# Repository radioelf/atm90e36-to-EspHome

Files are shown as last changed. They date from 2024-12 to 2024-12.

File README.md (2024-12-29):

Código para el IC ATM90e36 para usar con EspHome

Code for the ATM90e36 IC to use with ESPHome

Creative Commons License Disclaimer

UNLESS OTHERWISE MUTUALLY AGREED TO BY THE PARTIES IN WRITING, LICENSOR OFFERS THE WORK AS-IS AND MAKES NO REPRESENTATIONS OR WARRANTIES OF ANY KIND CONCERNING THE WORK, EXPRESS, IMPLIED, STATUTORY OR OTHERWISE, INCLUDING, WITHOUT LIMITATION, WARRANTIES OF TITLE, MERCHANTIBILITY, FITNESS FOR A PARTICULAR PURPOSE, NONINFRINGEMENT, OR THE ABSENCE OF LATENT OR OTHER DEFECTS, ACCURACY, OR THE PRESENCE OF ABSENCE OF ERRORS, WHETHER OR NOT DISCOVERABLE. SOME JURISDICTIONS DO NOT ALLOW THE EXCLUSION OF IMPLIED WARRANTIES, SO SUCH EXCLUSION MAY NOT APPLY TO YOU. EXCEPT TO THE EXTENT REQUIRED BY APPLICABLE LAW, IN NO EVENT WILL LICENSOR BE LIABLE TO YOU ON ANY LEGAL THEORY FOR ANY SPECIAL, INCIDENTAL, CONSEQUENTIAL, PUNITIVE OR EXEMPLARY DAMAGES ARISING OUT OF THIS LICENSE OR THE USE OF THE WORK, EVEN IF LICENSOR HAS BEEN ADVISED OF THE POSSIBILITY OF SUCH DAMAGES.

http://creativecommons.org/licenses/by-sa/3.0/

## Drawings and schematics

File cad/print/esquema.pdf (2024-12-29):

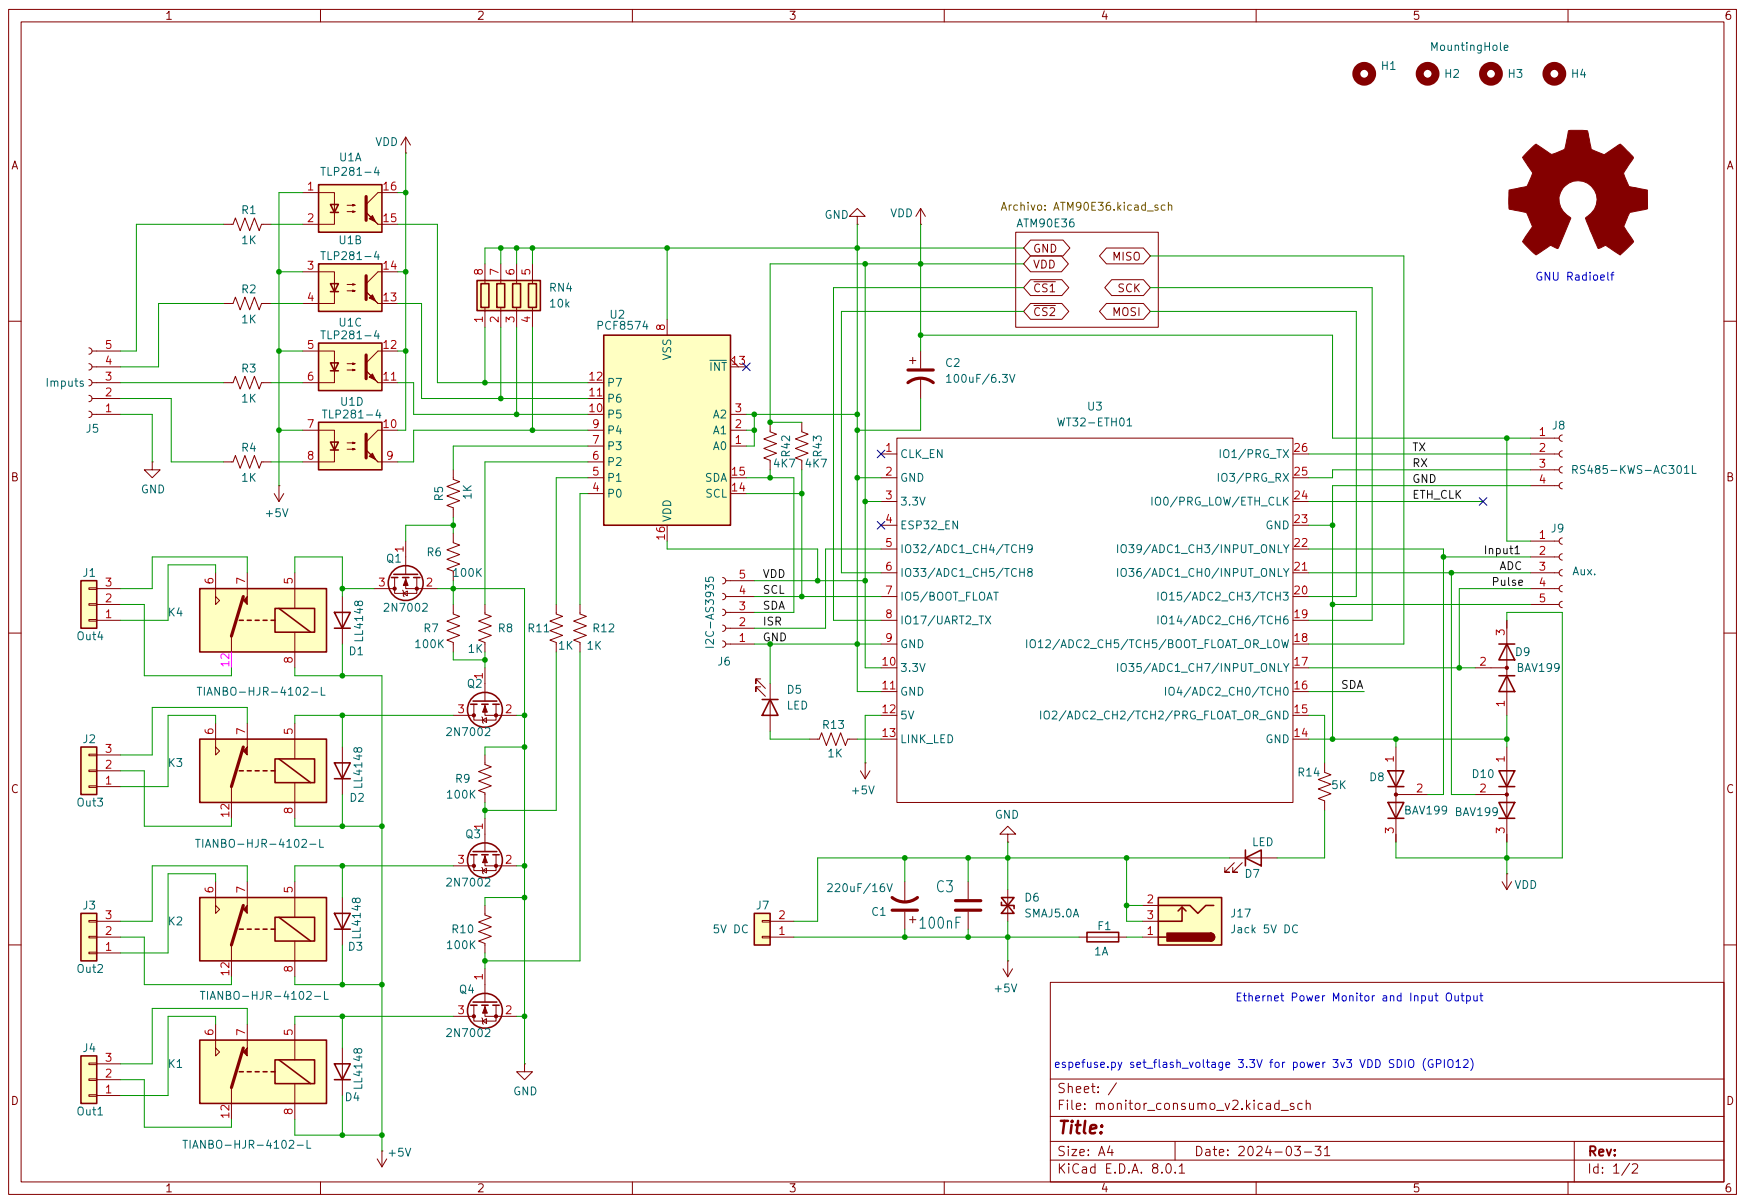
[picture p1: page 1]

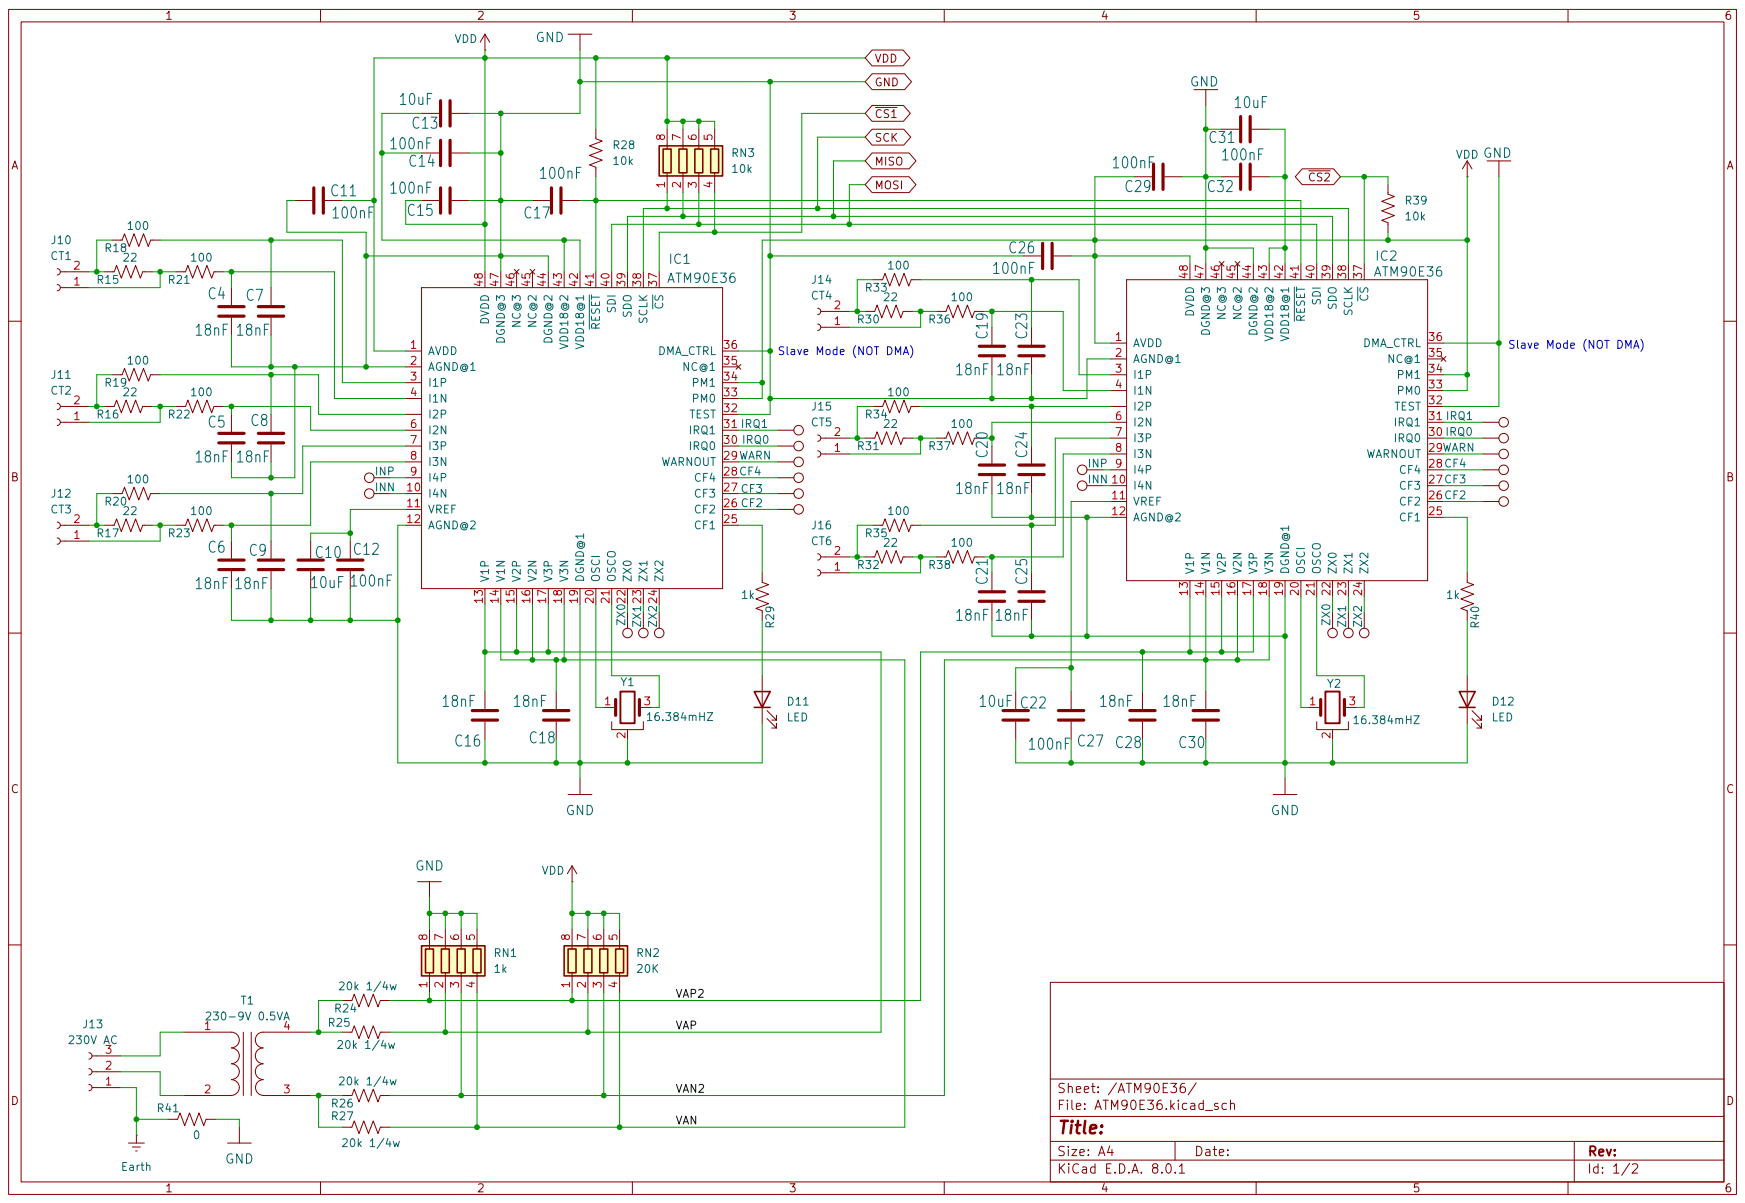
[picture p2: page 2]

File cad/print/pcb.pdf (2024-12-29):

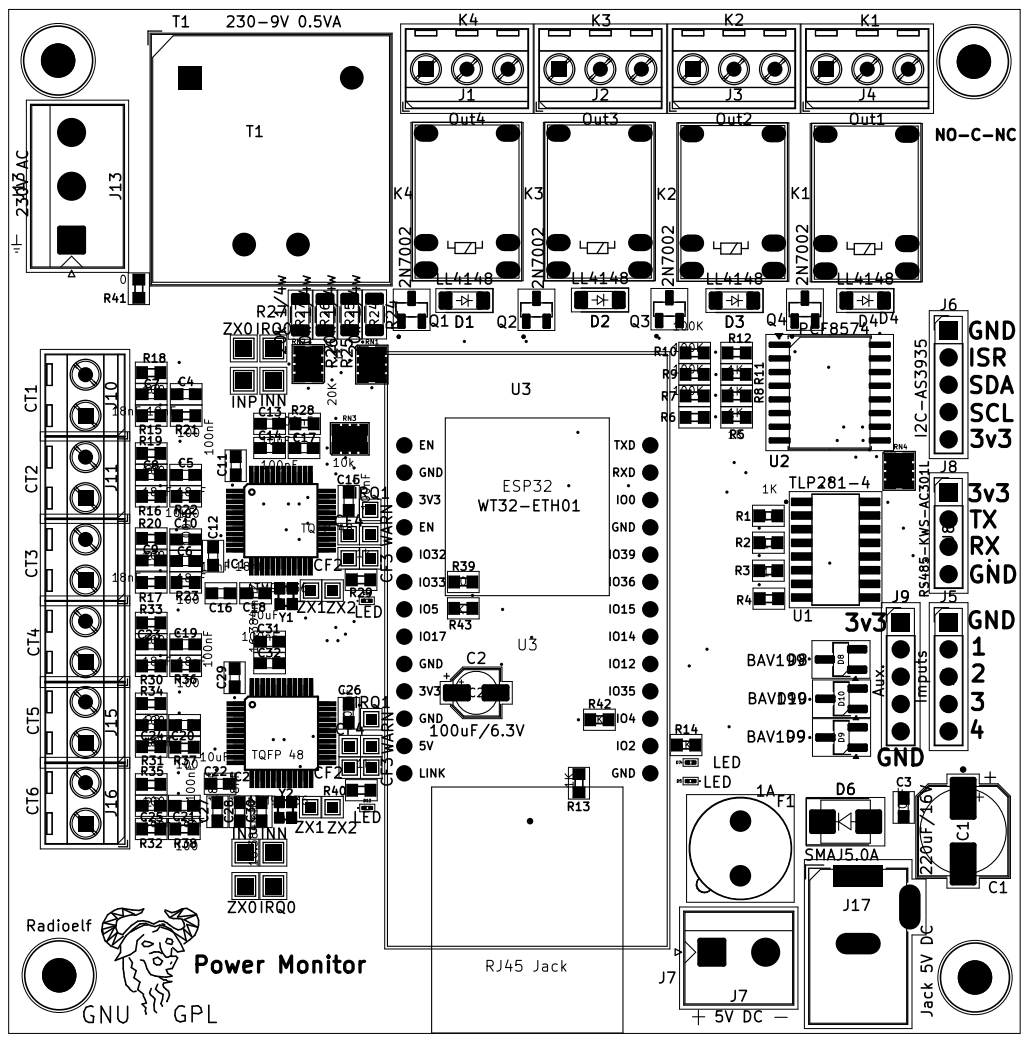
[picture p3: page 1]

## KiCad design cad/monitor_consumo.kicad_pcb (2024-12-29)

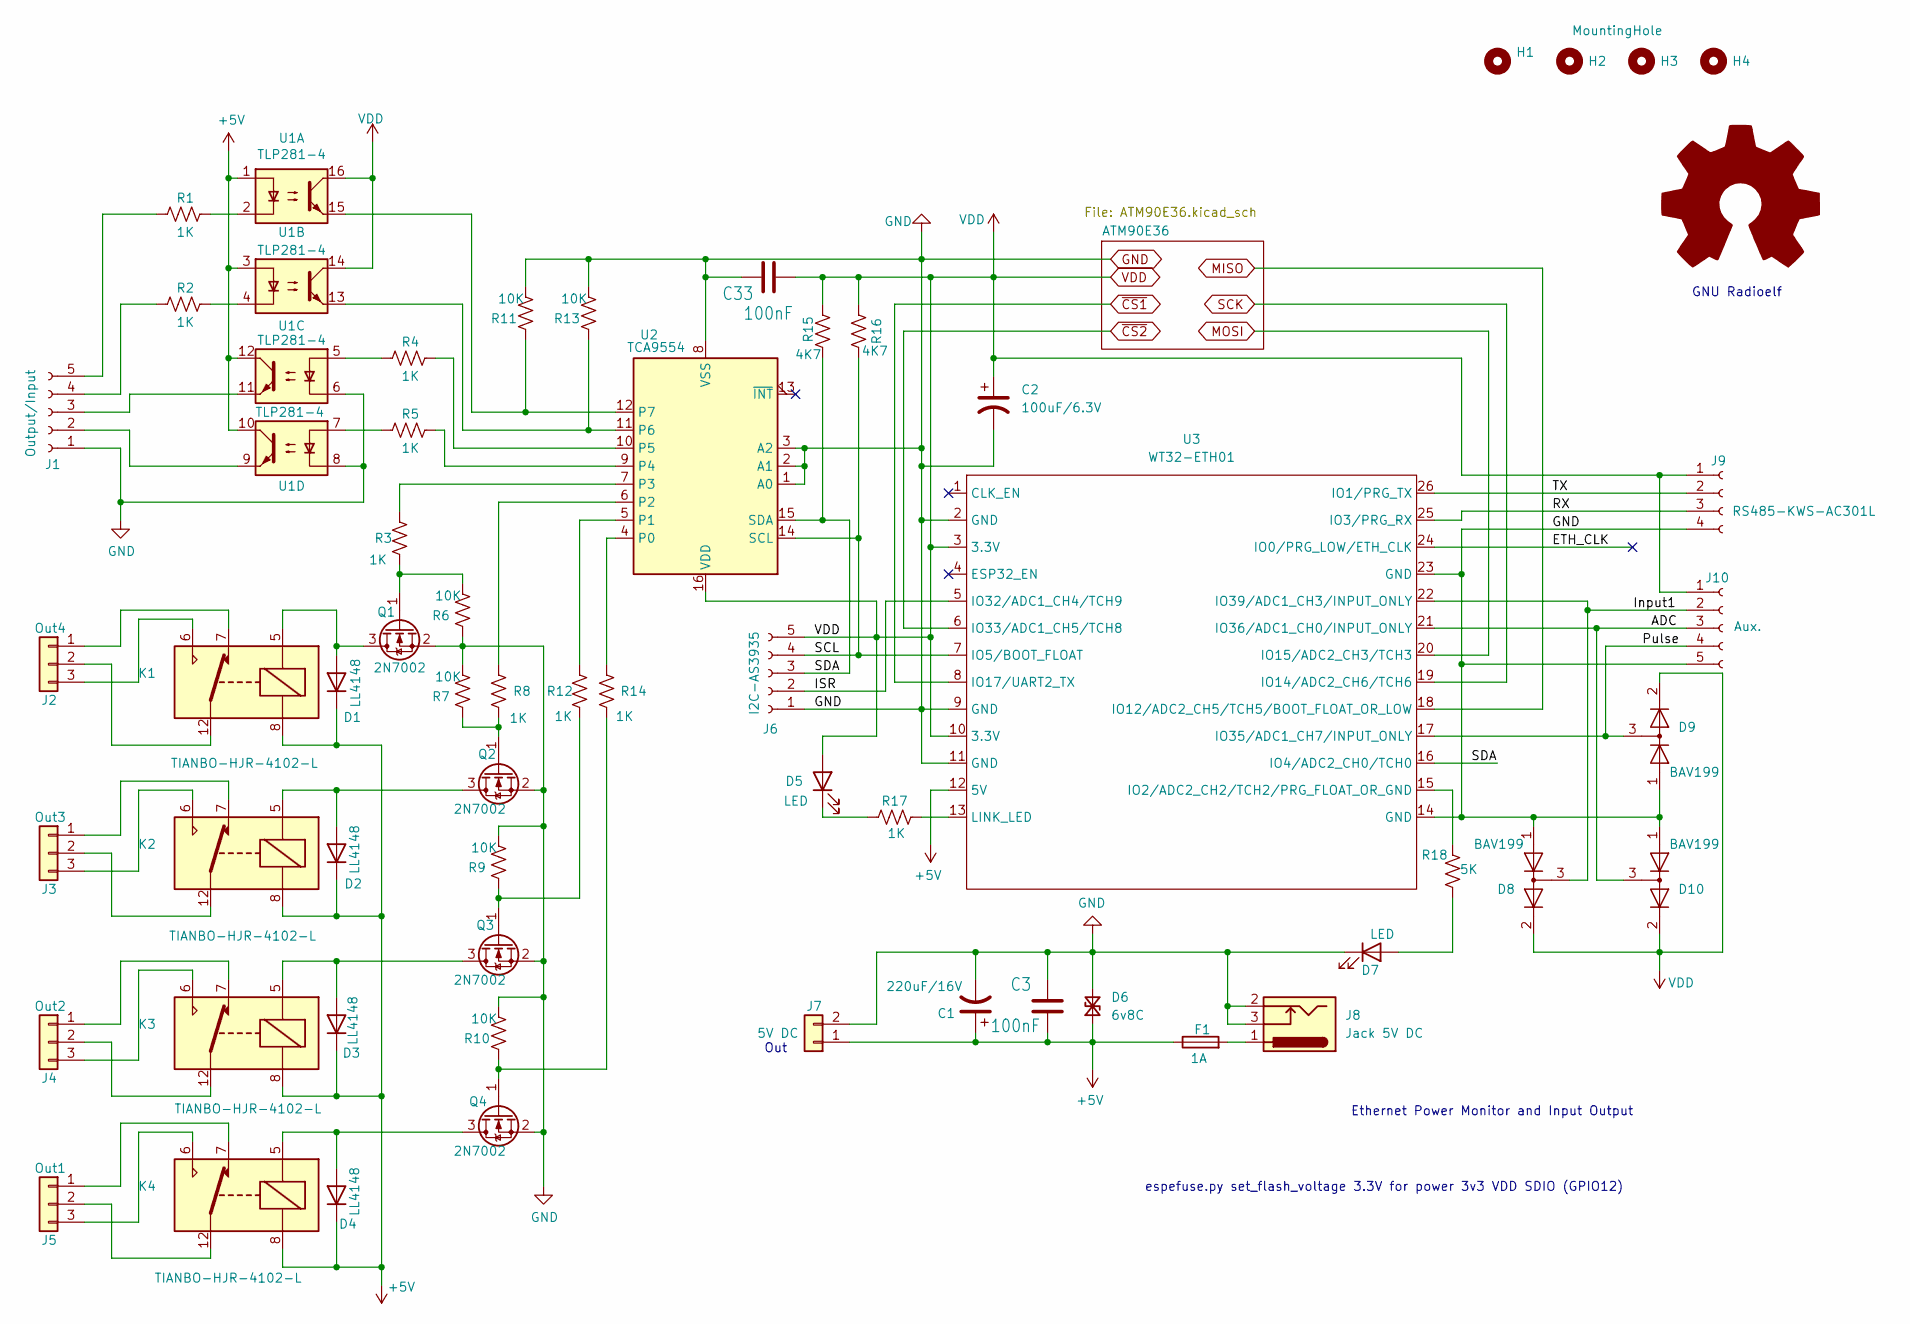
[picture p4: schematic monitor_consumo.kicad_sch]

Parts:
C1: 220uF/16V; CP_Elec_8x5.4
C2: 100uF/6.3V; CP_Elec_4x5.4
C3, C33: 100nF; C0603
D1, D2, D3, D4: LL4148; D_MiniMELF
D5, D7: LED; LED_0603_1608Metric
D6: 6v8C; D_SMB
D8, D9, D10: BAV199; SOT-23
F1: 1A; Fuseholder_TR5_Littelfuse_No560_No460
H1, H2, H3, H4: MountingHole; MountingHole_3.2mm_M3
J1: Output/Input; PinHeader_1x05_P2.54mm_Vertical
J2: Out4; TerminalBlock_Phoenix_PT-1,5-3-3.5-H_1x03_P3.50mm_Horizontal
J3: Out3; TerminalBlock_Phoenix_PT-1,5-3-3.5-H_1x03_P3.50mm_Horizontal
J4: Out2; TerminalBlock_Phoenix_PT-1,5-3-3.5-H_1x03_P3.50mm_Horizontal
J5: Out1; TerminalBlock_Phoenix_PT-1,5-3-3.5-H_1x03_P3.50mm_Horizontal
J6: I2C-AS3935; PinHeader_1x05_P2.54mm_Vertical
J7: 5V DC; JST_NV_B02P-NV_1x02_P5.00mm_Vertical
J8: Jack 5V DC; BarrelJack_GCT_DCJ200-10-A_Horizontal
J9: RS485-KWS-AC301L; PinHeader_1x04_P2.54mm_Vertical
J10: Aux.; PinHeader_1x05_P2.54mm_Vertical
K1, K2, K3, K4: TIANBO-HJR-4102-L; Relay_SPDT_HJR-4102
Q1, Q2, Q3, Q4: 2N7002; 2N7002-SOT95P240X111-3N
R1, R2, R3, R4, R5, R8, R12, R14, R17: 1K; R0603
R6, R7, R9, R10, R11, R13: 10K; R0603
R15, R16: 4K7; R0603
R18: 5K; R0603
U1: TLP281-4; SOIC127P700X210-16N
U2: TCA9554; SOIC-16W_7.5x10.3mm_P1.27mm
U3: WT32-ETH01

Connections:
+5V: C1.1, C3.2, D1.1 (K), D2.1 (K), D3.1 (K), D4.1 (K), D6.1 (A1), F1.1, J7.1, K1.8, K2.8, K3.8, K4.8, U1.1, U1.3, U1.10, U1.12, U3.12 (5V)
/ADC: D10.3 (K), J10.3, U3.21 (IO36/ADC1_CH0/INPUT_ONLY)
/ETH_CLK: U3.24 (IO0/PRG_LOW/ETH_CLK)
/ISR: J6.2, U3.5 (IO32/ADC1_CH4/TCH9)
/Input1: D8.3 (K), J10.2, U3.22 (IO39/ADC1_CH3/INPUT_ONLY)
/Pulse: D9.3 (K), J10.4, U3.17 (IO35/ADC1_CH7/INPUT_ONLY)
/RX: J9.3, U3.25 (IO3/PRG_RX)
/SCL: J6.4, R16.1, U2.14 (SCL), U3.7 (IO5/BOOT_FLOAT)
/SDA: J6.3, R15.1, U2.15 (SDA), U3.16 (IO4/ADC2_CH0/TCH0)
/TX: J9.2, U3.26 (IO1/PRG_TX)
GND: C1.2, C2.2, C3.1, C33.1, D6.2 (A2), D7.1 (K), D8.1 (K), D9.1 (K), D10.1 (K), J1.1, J6.1, J7.2, J8.2, J8.3, J9.4, J10.5, Q1.2 (S), Q2.2 (S), Q3.2 (S), Q4.2 (S), R6.1, R7.2, R9.2, R10.2, R11.2, R13.2, U1.6, U1.8, U2.1 (A0), U2.2 (A1), U2.3 (A2), U2.8 (VSS), U3.2 (GND), U3.9 (GND), U3.11 (GND), U3.14 (GND), U3.23 (GND); also elsewhere on the board
MISO: U3.18 (IO12/ADC2_CH5/TCH5/BOOT_FLOAT_OR_LOW); also elsewhere on the board
MOSI: U3.20 (IO15/ADC2_CH3/TCH3); also elsewhere on the board
unnamed: D1.2 (A), K1.5, Q1.3 (D)
unnamed: D2.2 (A), K2.5, Q2.3 (D)
unnamed: D3.2 (A), K3.5, Q3.3 (D)
unnamed: D4.2 (A), K4.5, Q4.3 (D)
unnamed: D5.1 (K), R17.1
unnamed: D7.2 (A), R18.1
unnamed: F1.2, J8.1
unnamed: J1.2, U1.9
unnamed: J1.3, U1.11
unnamed: J1.4, R2.2
unnamed: J1.5, R1.2
unnamed: J2.1, K1.7
unnamed: J2.2, K1.1, K1.12
unnamed: J2.3, K1.6
unnamed: J3.1, K2.7
unnamed: J3.2, K2.1, K2.12
unnamed: J3.3, K2.6
unnamed: J4.1, K3.7
unnamed: J4.2, K3.1, K3.12
unnamed: J4.3, K3.6
unnamed: J5.1, K4.7
unnamed: J5.2, K4.1, K4.12
unnamed: J5.3, K4.6
unnamed: Q1.1 (G), R3.1, R6.2
unnamed: Q2.1 (G), R7.1, R8.1
unnamed: Q3.1 (G), R9.1, R12.1
unnamed: Q4.1 (G), R10.1, R14.1
unnamed: R1.1, U1.2
unnamed: R2.1, U1.4
unnamed: R4.2, U1.5
unnamed: R5.2, U1.7
unnamed: R14.2, U2.4 (P0)
unnamed: R12.2, U2.5 (P1)
unnamed: R8.2, U2.6 (P2)
unnamed: R3.2, U2.7 (P3)
unnamed: R5.1, U2.9 (P4)
unnamed: R4.1, U2.10 (P5)
unnamed: R13.1, U1.13, U2.11 (P6)
unnamed: R11.1, U1.15, U2.12 (P7)
unnamed: R18.2, U3.15 (IO2/ADC2_CH2/TCH2/PRG_FLOAT_OR_GND)
unnamed: R17.2, U3.13 (LINK_LED)
SCK: U3.19 (IO14/ADC2_CH6/TCH6); also elsewhere on the board
VDD: C2.1, C33.2, D5.2 (A), D8.2 (A), D9.2 (A), D10.2 (A), J6.5, J9.1, J10.1, R15.2, R16.2, U1.14, U1.16, U2.16 (VDD), U3.3 (3.3V), U3.10 (3.3V); also elsewhere on the board
~CS1: U3.8 (IO17/UART2_TX); also elsewhere on the board
~CS2: U3.6 (IO33/ADC1_CH5/TCH8); also elsewhere on the board

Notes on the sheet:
GNU Radioelf
espefuse.py set_flash_voltage 3.3V for power 3v3 VDD SDIO (GPIO12)
Out
Ethernet Power Monitor and Input Output

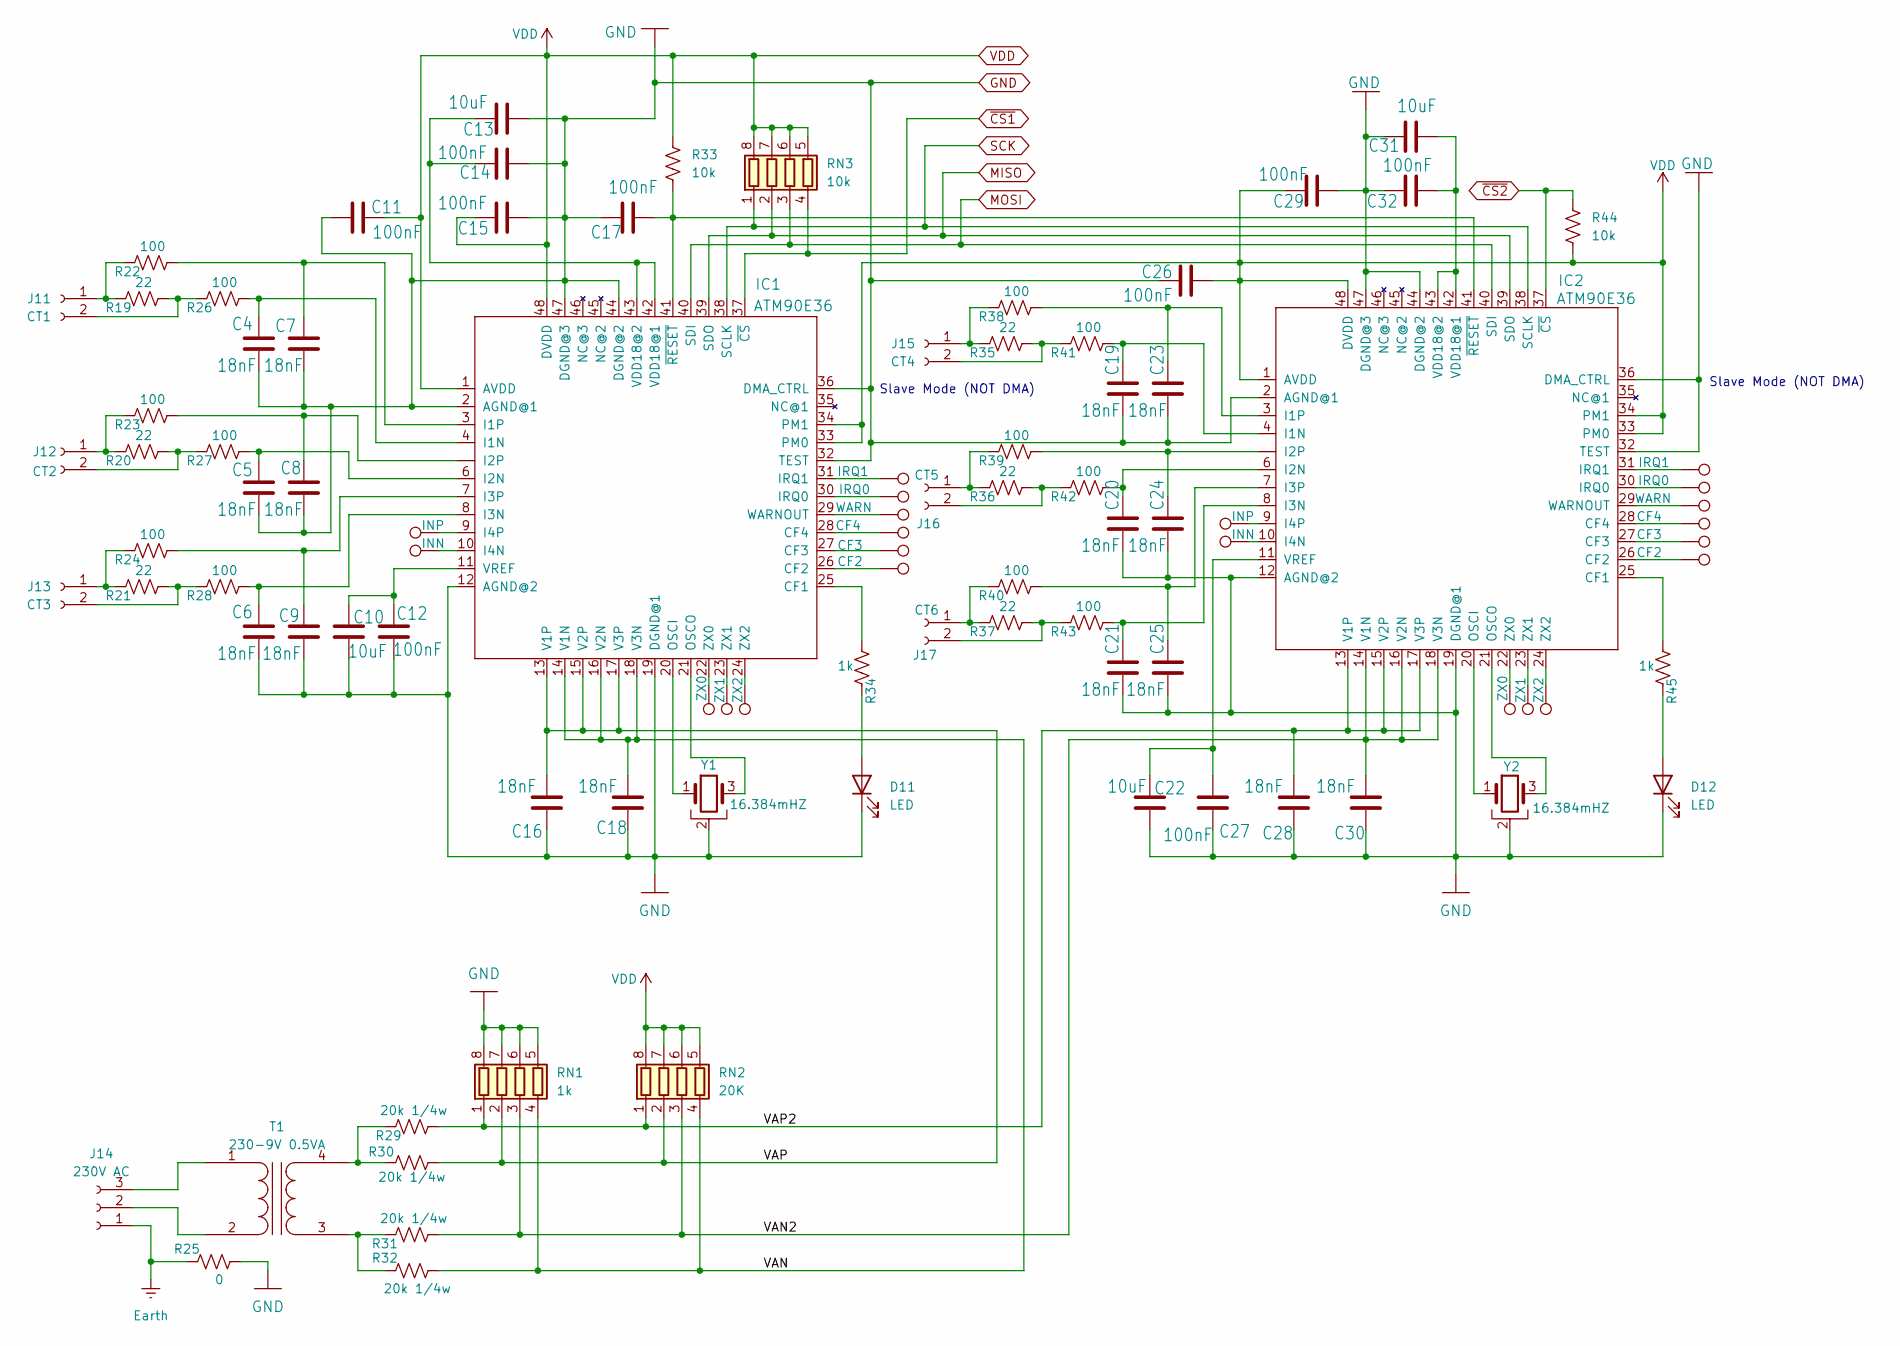
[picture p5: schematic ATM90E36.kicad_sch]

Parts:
C4, C5, C6, C7, C8, C9, C16, C18, C19, C20, C21, C23, C24, C25, C28, C30: 18nF; C0603
C10, C13, C22, C31: 10uF; C0603
C11, C12, C14, C15, C17, C26, C27, C29, C32: 100nF; C0603
D11, D12: LED; LED_0603_1608Metric
IC1, IC2: ATM90E36; TQFP48
J11: CT1; TerminalBlock_Phoenix_PT-1,5-2-3.5-H_1x02_P3.50mm_Horizontal
J12: CT2; TerminalBlock_Phoenix_PT-1,5-2-3.5-H_1x02_P3.50mm_Horizontal
J13: CT3; TerminalBlock_Phoenix_PT-1,5-2-3.5-H_1x02_P3.50mm_Horizontal
J14: 230V AC; JST_NV_B03P-NV_1x03_P5.00mm_Vertical
J15: CT4; TerminalBlock_Phoenix_PT-1,5-2-3.5-H_1x02_P3.50mm_Horizontal
J16: CT5; TerminalBlock_Phoenix_PT-1,5-2-3.5-H_1x02_P3.50mm_Horizontal
J17: CT6; TerminalBlock_Phoenix_PT-1,5-2-3.5-H_1x02_P3.50mm_Horizontal
R19, R20, R21, R35, R36, R37: 22; R0603
R22, R23, R24, R26, R27, R28, R38, R39, R40, R41, R42, R43: 100; R0603
R25: 0; R0603
R29, R30, R31, R32: 20k 1/4w; R_1206_3216Metric
R33, R44: 10k; R0603
R34, R45: 1k; R0603
RN1: 1k; RA1206-8
RN2: 20K; RA1206-8
RN3: 10k; RA1206-8
T1: 230-9V 0.5VA; Transformer_hr-diemen-efiter_E2010054
TP1, TP12: INP; TestPoint_THTPad_1.5x1.5mm_Drill0.7mm
TP2, TP13: INN; TestPoint_THTPad_1.5x1.5mm_Drill0.7mm
TP3, TP14: ZX0; TestPoint_THTPad_1.5x1.5mm_Drill0.7mm
TP4, TP15: ZX1; TestPoint_Pad_1.0x1.0mm
TP5, TP16: ZX2; TestPoint_Pad_1.0x1.0mm
TP6, TP17: IRQ1; TestPoint_Pad_1.0x1.0mm
TP7, TP18: IRQ0; TestPoint_THTPad_1.5x1.5mm_Drill0.7mm
TP8, TP19: WARN; TestPoint_Pad_1.0x1.0mm
TP9, TP20: CF4; TestPoint_Pad_1.0x1.0mm
TP10, TP21: CF3; TestPoint_Pad_1.0x1.0mm
TP11, TP22: CF2; TestPoint_Pad_1.0x1.0mm
Y1, Y2: 16.384mHZ; Crystal_SMD_EuroQuartz_MT-4Pin_3.2x2.5mm_HandSoldering

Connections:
/ATM90E36/VAN: C18.1, IC1.14 (V1N), IC1.16 (V2N), IC1.18 (V3N), R32.2, RN1.4 (R4.1), RN2.4 (R4.1)
/ATM90E36/VAN2: C30.1, IC2.14 (V1N), IC2.16 (V2N), IC2.18 (V3N), R31.2, RN1.3 (R3.1), RN2.3 (R3.1)
/ATM90E36/VAP: C16.1, IC1.13 (V1P), IC1.15 (V2P), IC1.17 (V3P), R30.2, RN1.2 (R2.1), RN2.2 (R2.1)
/ATM90E36/VAP2: C28.1, IC2.13 (V1P), IC2.15 (V2P), IC2.17 (V3P), R29.2, RN1.1 (R1.1), RN2.1 (R1.1)
Earth: J14.1, R25.1
GND: C4.1, C5.1, C6.1, C7.1, C8.1, C9.1, C10.2, C11.1, C12.2, C13.1, C14.1, C15.1, C16.2, C17.1, C18.2, C19.1, C20.1, C21.1, C22.2, C23.1, C24.1, C25.1, C26.1, C27.2, C28.2, C29.1, C30.2, C31.2, C32.2, D11.1 (K), D12.1 (K), IC1.2 (AGND@1), IC1.12 (AGND@2), IC1.19 (DGND@1), IC1.32 (TEST), IC1.36 (DMA_CTRL), IC1.44 (DGND@2), IC1.47 (DGND@3), IC2.2 (AGND@1), IC2.12 (AGND@2), IC2.19 (DGND@1), IC2.32 (TEST), IC2.36 (DMA_CTRL), IC2.44 (DGND@2), IC2.47 (DGND@3), R25.2, RN1.5 (R4.2), RN1.6 (R3.2), RN1.7 (R2.2), RN1.8 (R1.2), Y1.2, Y1.4, Y2.2, Y2.4; also elsewhere on the board
MISO: IC1.39 (SDO), IC2.39 (SDO), RN3.2 (R2.1); also elsewhere on the board
MOSI: IC1.40 (SDI), IC2.40 (SDI), RN3.3 (R3.1); also elsewhere on the board
unnamed: D11.2 (A), R34.1
unnamed: D12.2 (A), R45.1
unnamed: IC1.25 (CF1), R34.2
unnamed: IC1.26 (CF2), TP11.1
unnamed: IC1.27 (CF3), TP10.1
unnamed: IC1.28 (CF4), TP9.1
unnamed: C4.2, IC1.4 (I1N), R26.2
unnamed: C7.2, IC1.3 (I1P), R22.2
unnamed: C5.2, IC1.6 (I2N), R27.2
unnamed: C8.2, IC1.5 (I2P), R23.2
unnamed: C6.2, IC1.8 (I3N), R28.2
unnamed: C9.2, IC1.7 (I3P), R24.2
unnamed: IC1.10 (I4N), TP2.1
unnamed: IC1.9 (I4P), TP1.1
unnamed: IC1.30 (IRQ0), TP7.1
unnamed: IC1.31 (IRQ1), TP6.1
unnamed: IC1.20 (OSCI), Y1.1
unnamed: IC1.21 (OSCO), Y1.3
unnamed: C13.2, C14.2, IC1.42 (VDD18@1), IC1.43 (VDD18@2)
unnamed: C10.1, C12.1, IC1.11 (VREF)
unnamed: IC1.29 (WARNOUT), TP8.1
unnamed: IC1.22 (ZX0), TP3.1
unnamed: IC1.23 (ZX1), TP4.1
unnamed: IC1.24 (ZX2), TP5.1
unnamed: C17.2, IC1.41 (~RESET), IC2.41 (~RESET), R33.2
unnamed: IC2.25 (CF1), R45.2
unnamed: IC2.26 (CF2), TP22.1
unnamed: IC2.27 (CF3), TP21.1
unnamed: IC2.28 (CF4), TP20.1
unnamed: C19.2, IC2.4 (I1N), R41.2
unnamed: C23.2, IC2.3 (I1P), R38.2
unnamed: C20.2, IC2.6 (I2N), R42.2
unnamed: C24.2, IC2.5 (I2P), R39.2
unnamed: C21.2, IC2.8 (I3N), R43.2
unnamed: C25.2, IC2.7 (I3P), R40.2
unnamed: IC2.10 (I4N), TP13.1
unnamed: IC2.9 (I4P), TP12.1
unnamed: IC2.30 (IRQ0), TP18.1
unnamed: IC2.31 (IRQ1), TP17.1
unnamed: IC2.20 (OSCI), Y2.1
unnamed: IC2.21 (OSCO), Y2.3
unnamed: C31.1, C32.1, IC2.42 (VDD18@1), IC2.43 (VDD18@2)
unnamed: C22.1, C27.1, IC2.11 (VREF)
unnamed: IC2.29 (WARNOUT), TP19.1
unnamed: IC2.22 (ZX0), TP14.1
unnamed: IC2.23 (ZX1), TP15.1
unnamed: IC2.24 (ZX2), TP16.1
unnamed: J11.1, R19.1, R22.1
unnamed: J11.2, R19.2, R26.1
unnamed: J12.1, R20.1, R23.1
unnamed: J12.2, R20.2, R27.1
unnamed: J13.1, R21.1, R24.1
unnamed: J13.2, R21.2, R28.1
unnamed: J14.2, T1.2 (AB)
unnamed: J14.3, T1.1 (AA)
unnamed: J15.1, R35.1, R38.1
unnamed: J15.2, R35.2, R41.1
unnamed: J16.1, R36.1, R39.1
unnamed: J16.2, R36.2, R42.1
unnamed: J17.1, R37.1, R40.1
unnamed: J17.2, R37.2, R43.1
unnamed: R31.1, R32.1, T1.3 (SA)
unnamed: R29.1, R30.1, T1.4 (SB)
SCK: IC1.38 (SCLK), IC2.38 (SCLK), RN3.1 (R1.1); also elsewhere on the board
VDD: C11.2, C15.2, C26.2, C29.2, IC1.1 (AVDD), IC1.33 (PM0), IC1.34 (PM1), IC1.48 (DVDD), IC2.1 (AVDD), IC2.33 (PM0), IC2.34 (PM1), IC2.48 (DVDD), R33.1, R44.1, RN2.5 (R4.2), RN2.6 (R3.2), RN2.7 (R2.2), RN2.8 (R1.2), RN3.5 (R4.2), RN3.6 (R3.2), RN3.7 (R2.2), RN3.8 (R1.2); also elsewhere on the board
~CS1: IC1.37 (~CS), RN3.4 (R4.1); also elsewhere on the board
~CS2: IC2.37 (~CS), R44.2; also elsewhere on the board

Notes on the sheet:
Slave Mode (NOT DMA)

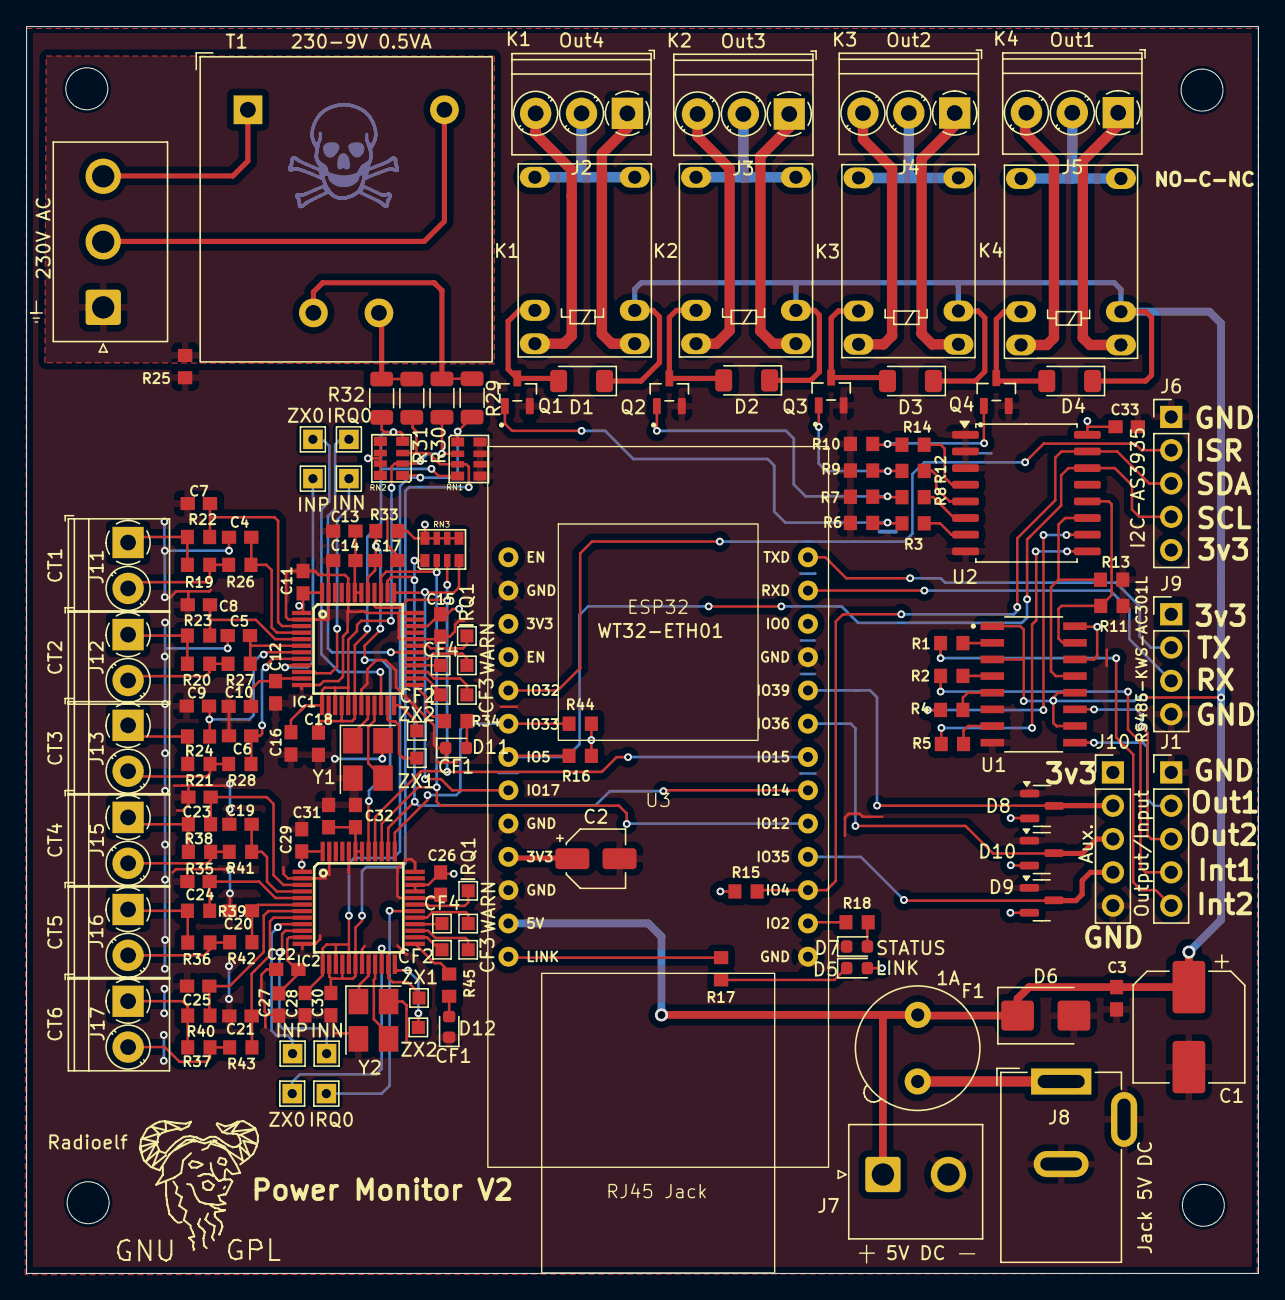
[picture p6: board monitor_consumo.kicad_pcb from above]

Board: 2 copper layers, 94.0 x 95.1 mm, 154 parts (0 on the bottom side), 125 nets.

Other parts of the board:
Radioelf: GNU-Logo; Symbol_GNU-Logo_SilkscreenTop

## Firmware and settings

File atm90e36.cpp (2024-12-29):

// Beta version, data retrieval still needs to be verified...
#include "atm90e36.h"
#include "atm90e36_reg.h"
#include "esphome/core/log.h"
#include <cinttypes>

namespace esphome {
namespace atm90e36 {

static const char *const TAG = "atm90e36";
void ATM90E36Component::loop() {
  if (this->get_publish_interval_flag_()) {
    this->set_publish_interval_flag_(false);
    for (uint8_t phase = 0; phase < 3; phase++) {
      if (this->phase_[phase].voltage_sensor_ != nullptr) {
        this->phase_[phase].voltage_ = this->get_phase_voltage_(phase);
      }
    }
    for (uint8_t phase = 0; phase < 3; phase++) {
      if (this->phase_[phase].current_sensor_ != nullptr) {
        this->phase_[phase].current_ = this->get_phase_current_(phase);
      }
    }
    for (uint8_t phase = 0; phase < 3; phase++) {
      if (this->phase_[phase].power_sensor_ != nullptr) {
        this->phase_[phase].active_power_ = this->get_phase_active_power_(phase);
      }
    }
    for (uint8_t phase = 0; phase < 3; phase++) {
      if (this->phase_[phase].power_factor_sensor_ != nullptr) {
        this->phase_[phase].power_factor_ = this->get_phase_power_factor_(phase);
      }
    }
    for (uint8_t phase = 0; phase < 3; phase++) {
      if (this->phase_[phase].reactive_power_sensor_ != nullptr) {
        this->phase_[phase].reactive_power_ = this->get_phase_reactive_power_(phase);
      }
    }
    for (uint8_t phase = 0; phase < 3; phase++) {
      if (this->phase_[phase].apparent_power_sensor_ != nullptr) {
        this->phase_[phase].apparent_power_ = this->get_phase_apparent_power_(phase);
      }
    }
/*
    if (this->total_active_power_ != nullptr) {
      this->total_active_power_->publish_state(this->get_total_active_power_());
    }
        if (this->total_reactive_power_ != nullptr) {
      this->total_reactive_power_->publish_state(this->get_total_reactive_power_()());
    }
        if (this->total_apparent_power_ != nullptr) {
      this->total_apparent_power_->publish_state(this->get_total_apparent_power_());
    }
*/
    for (uint8_t phase = 0; phase < 3; phase++) {
      if (this->phase_[phase].forward_active_energy_sensor_ != nullptr) {
        this->phase_[phase].forward_active_energy_ = this->get_phase_forward_active_energy_(phase);
      }
    }
    for (uint8_t phase = 0; phase < 3; phase++) {
      if (this->phase_[phase].reverse_active_energy_sensor_ != nullptr) {
        this->phase_[phase].reverse_active_energy_ = this->get_phase_reverse_active_energy_(phase);
      }
    }
    for (uint8_t phase = 0; phase < 3; phase++) {
      if (this->phase_[phase].phase_angle_sensor_ != nullptr) {
        this->phase_[phase].phase_angle_ = this->get_phase_angle_(phase);
      }
    }
    for (uint8_t phase = 0; phase < 3; phase++) {
      if (this->phase_[phase].harmonic_active_power_sensor_ != nullptr) {
        this->phase_[phase].harmonic_active_power_ = this->get_phase_harmonic_active_power_(phase);
      }
    }
    for (uint8_t phase = 0; phase < 3; phase++) {
      if (this->phase_[phase].peak_current_sensor_ != nullptr) {
        this->phase_[phase].peak_current_ = this->get_phase_peak_current_(phase);
      }
    }
    for (uint8_t phase = 0; phase < 3; phase++) {
      if (this->phase_[phase].voltage_sensor_ != nullptr) {
        this->phase_[phase].voltage_sensor_->publish_state(this->get_local_phase_voltage_(phase));
      }
    }
    for (uint8_t phase = 0; phase < 3; phase++) {
      if (this->phase_[phase].current_sensor_ != nullptr) {
        this->phase_[phase].current_sensor_->publish_state(this->get_local_phase_current_(phase));
      }
    }
    for (uint8_t phase = 0; phase < 3; phase++) {
      if (this->phase_[phase].power_sensor_ != nullptr) {
        this->phase_[phase].power_sensor_->publish_state(this->get_local_phase_active_power_(phase));
      }
    }
    for (uint8_t phase = 0; phase < 3; phase++) {
      if (this->phase_[phase].power_factor_sensor_ != nullptr) {
        this->phase_[phase].power_factor_sensor_->publish_state(this->get_local_phase_power_factor_(phase));
      }
    }
    for (uint8_t phase = 0; phase < 3; phase++) {
      if (this->phase_[phase].reactive_power_sensor_ != nullptr) {
        this->phase_[phase].reactive_power_sensor_->publish_state(this->get_local_phase_reactive_power_(phase));
      }
    }
    for (uint8_t phase = 0; phase < 3; phase++) {
      if (this->phase_[phase].apparent_power_sensor_ != nullptr) {
        this->phase_[phase].apparent_power_sensor_->publish_state(this->get_local_phase_apparent_power_(phase));
      }
    }
    for (uint8_t phase = 0; phase < 3; phase++) {
      if (this->phase_[phase].forward_active_energy_sensor_ != nullptr) {
        this->phase_[phase].forward_active_energy_sensor_->publish_state(
            this->get_local_phase_forward_active_energy_(phase));
      }
    }
    for (uint8_t phase = 0; phase < 3; phase++) {
      if (this->phase_[phase].reverse_active_energy_sensor_ != nullptr) {
        this->phase_[phase].reverse_active_energy_sensor_->publish_state(
            this->get_local_phase_reverse_active_energy_(phase));
      }
    }
    for (uint8_t phase = 0; phase < 3; phase++) {
      if (this->phase_[phase].phase_angle_sensor_ != nullptr) {
        this->phase_[phase].phase_angle_sensor_->publish_state(this->get_local_phase_angle_(phase));
      }
    }
    for (uint8_t phase = 0; phase < 3; phase++) {
      if (this->phase_[phase].harmonic_active_power_sensor_ != nullptr) {
        this->phase_[phase].harmonic_active_power_sensor_->publish_state(
            this->get_local_phase_harmonic_active_power_(phase));
      }
    }
    for (uint8_t phase = 0; phase < 3; phase++) {
      if (this->phase_[phase].peak_current_sensor_ != nullptr) {
        this->phase_[phase].peak_current_sensor_->publish_state(this->get_local_phase_peak_current_(phase));
      }
    }
    if (this->freq_sensor_ != nullptr) {
      this->freq_sensor_->publish_state(this->get_frequency_());
    }
    if (this->chip_temperature_sensor_ != nullptr) {
      this->chip_temperature_sensor_->publish_state(this->get_chip_temperature_());
    }
  }
}

void ATM90E36Component::update() {
  if (this->read16_(ATM90E36_REGISTER_CONFIGSTART) != 0x8765) { //0x5678) {
    this->status_set_warning();
    ESP_LOGCONFIG(TAG, "Respuesta REGISTER_CONFIGSTART erronea...");
    return;
  }
  this->set_publish_interval_flag_(true);
  this->status_clear_warning();
}
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

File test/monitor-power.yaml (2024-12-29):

# WT32-ETH01
#    GPIO  0: Modo de reloj para el bus RMII LAN8720 ->debe ser LOW para entrar en modo de arranque -BOOT
#    GPIO  1: TXD 
#    GPIO  2: LED estado  ->debe estar flotante o LOW durante el arranque -BOOT
#    GPIO  3: RXD 
#    GPIO  4: I2C SDA
#    GPIO  5: I2C SCL -HIGH durante el reinicio ->debe estar HIGH durante el arranque -BOOT
#    GPIO  6, 7, 8, 9, 10, Y 11  (SPI chip flash) (6-11 -HIGH durante el reinicio) *
# Ejecutar espefuse.py set_flash_voltage 3.3V para power 3v3 VDD SDIO y liberar GPIO12
#    GPIO 12: MISO (Master In Slave Out) atm90e36 -HIGH durante el reinicio ->debe estar en estado ALTO durante el arranque -BOOT
#    GPIO 13: *
#    GPIO 14: SCK (Serial Clock) atm90e36 -HIGH durante el reinicio
#    GPIO 15: MOSI (Master Out Slave In) atm90e32 (debe ser LOW durante el arranque)
#    GPIO 16: Power_pin del LAN8720 *
#    GPIO 17: CS1 (Slave Select) atm90e36
#    GPIO 18: Datos de gestión LAN8720 *
#    GPIO 19: TXD[0] bus RMII LAN8720 *
#    GPIO 21: TX_EN bus RMII LAN8720 *
#    GPIO 22: TXD[1] bus RMII LAN8720 *
#    GPIO 23: Control de datos de gestión LAN8720 *
#    GPIO 25: RXD[0] bus RMII LAN8720 *
#    GPIO 26: RXD[1] bus RMII LAN8720 *
#    GPIO 27: CRS_DV bus RMII LAN8720 *
#    GPIO 32: ISR  as3935
#    GPIO 33: CS2 (Slave Select) atm90e32 (segundo)
#    GPIO 34: * (SOLO input) NO soporta Pull-Up
#    GPIO 35: Contador pulsos caudalímetro (SOLO input) NO soporta Pull-Up
#    GPIO 36: ADC medidor presión. NO soporta Pull-Up
#    GPIO 39: Entrada llamada interfono (SOLO input) NO soporta Pull-Up 
# * NO ACCESIBLES EN EL MODULO WT32-ETH01
#
# Descripciones de Registros TCA9554
# El registro de Puerto de Entrada (registro 0) refleja los niveles lógicos entrantes de los pines,
# independientemente de si el pin está definido como entrada o salida por el registro de Configuración.
# Solo actúa en la operación de lectura. Las escrituras en estos registros no tienen ningún efecto. 
# El valor predeterminado, X, se determina por el nivel lógico aplicado externamente. Ver Tabla 
# Register 0 (Input Port Register)
# BIT     I7 I6 I5 I4 I3 I2 I1 I0
# DEFAULT X  X  X  X  X  X  X  X
# Antes de una operación de lectura, se envía una transmisión de escritura con el byte de comando 
# para indicarle al dispositivo I2C que se accederá a continuación al registro de Puerto de Entrada.
# El registro de Puerto de Salida (registro 1) muestra los niveles lógicos salientes de los pines 
# definidos como salidas por el registro de Configuración. Los valores de los bits en este registro
# no tienen efecto en los pines definidos como entradas.
# A su vez, las lecturas de este registro reflejan el valor que está en el flip-flop que controla 
# la selección de salida, no el valor real del pin. Ver Tabla
# Register 1 (Output Port Register) 
# BIT     O7 O6 O5 O4 O3 O2 O1 O0
# DEFAULT 1  1  1  1  1  1  1  1
# El registro de Inversión de Polaridad (registro 2) permite la inversión de polaridad de los pines
# definidos como entradas por el registro de Configuración. Si un bit en este registro está configurado
# (escrito con 1), la polaridad del pin del puerto correspondiente se invierte. Si un bit en este registro
# se borra (escrito con un 0), se conserva la polaridad original del pin del puerto. Ver Tabla 
# Register 2 (Polarity Inversion Register) 
# BIT     N7 N6 N5 N4 N3 N2 N1 N0
# DEFAULT 0  0  0  0  0  0  0  0
# El registro de Configuración (registro 3) define la dirección de los pines de E/S (Entrada/Salida). 
# Si un bit en este registro se establece a 1, el pin del puerto correspondiente se habilita como una
# entrada con un controlador de salida de alta impedancia. Si un bit en este registro se borra a 0, 
# el pin del puerto correspondiente se habilita como una salida. Ver Tabla
# Register 3 (Configuration Register) 
# BIT     C7 C6 C5 C4 C3 C2 C1 C0
# DEFAULT 1  1  1  1  1  1  1  1

# Información
esphome:
  name: monitor-power
  friendly_name: monitor_power
  project:
    name: radioelf.monitor
    version: "0.2.2_b"  

# Tipo ESP32
esp32:
  board: esp32dev  # WT32-ETH01
  framework:
    type: arduino

# Componente local para atm90e36
external_components:
  - source: ~/config/local_components/ # /local_components/atm90e36/atm90e36.cpp ...

# Servidor WEB
web_server:
  port: 80

# Módulo RS232 
uart:
  id: debug_serie
  tx_pin: 1
  rx_pin: 3
  baud_rate: 115200
  data_bits: 8
  stop_bits: 1
  parity: NONE

# Logger
logger:
  level: ERROR # DEBUG 

# Configuración para el bus I2C para TCA9554 y as3935
i2c:
  sda: GPIO4
  scl: GPIO5
  scan: false
  id: bus_i2c

# Expansor dirección TCA9554A 0 1 1 1 A2 A1 A0 R/W -> 0111000 x (A0, A1 y A2 a GND)
pca9554:
    id: 'expand_gpio'
    address: 0x38   # TCA9554A -> S-0111000 -R/W

# Configuración para el bus SPI atm90e36
spi:
  clk_pin: GPIO14  # SCLK
  miso_pin: GPIO12 # SDO
  mosi_pin: GPIO15 # SDI
  interface: software
  id: spi_bus
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
